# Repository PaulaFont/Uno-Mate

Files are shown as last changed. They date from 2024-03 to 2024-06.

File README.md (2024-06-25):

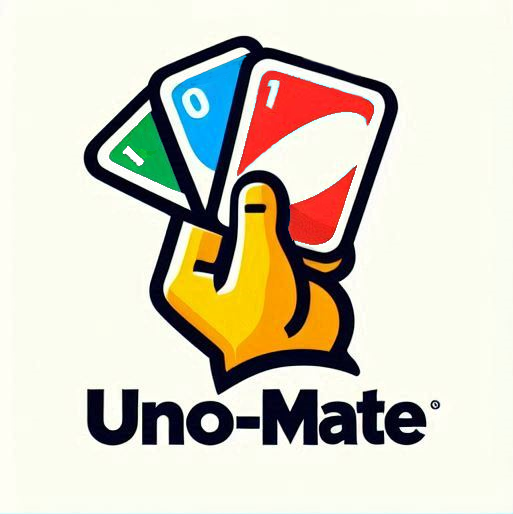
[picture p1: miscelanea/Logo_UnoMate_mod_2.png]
# Uno-Mate 

## Contendio del repositorio
- **3D_files**: Directorio que contiene todos los ficheros relativos al diseño 3D del robot
- **Fritzing**: Dentro de este tenemos todo el prototipaje de conexiones hecho en simulación
- **Pressupostos**: En el interior podemos encontrar los ficheros con la lista de componentes y sus respectivos precios
- **Sprints**: Aquí se encuentran todos los documentos relativos a los sprints
- **miscelanea**: Carpeta donde se encuentra archivos de recursos para el proyecto
- **src**: En esta carpeta es donde tenemos el código de nuestro robot

## Descripción del repositorio
### Contenido

1. [Descripcion](#descripcion)
2. [Como jugar una partida](#como-jugar-una-partida)
3. [Herramientas Software utilizadas](#herramientas-software-utilizadas)
4. [Esquema conexiones](#esquema-conexiones)
5. [Ficheros 3D](#ficheros-3d)
6. [Referencias](#referencias)
7. [Autores](#autores)

## Descripcion
<div style="text-align: justify;">

El objetivo del proyecto consiste en hacer el monitoreo de una partida del UNO, una de las cosas principales que hacemos en el proyecto es mirar cada una de las cartas que se van tirando en cada turno y por quién son tiradas, además de controlar si se hacen trampas o no. A más, otros objetivos del robot es que sea posible mezclar, repartir y dar diferentes cartas a los jugadores.

Para hacer el monitoreo de la partida lo que hemos hecho ha sido diferentes algoritmos. Uno que nos permite recortar la carta que está arriba del montón, y otros dos que nos permiten reconocer el número de la carta y el color de la carta.
Para hacer estos algoritmos hemos tenido que entrenar diferentes modelos. Para esto tuvimos que hacer un conjunto de datos customizado, ya que no encontrábamos ningún conjunto de datos que se ajustara a nuestra situación de las cartas del Uno. 

La funcionalidad de mezclar está diseñada para mezclar las cartas que se encuentran en las dos cajas laterales. En la caja de almacenaje de cartas (ubicada en el medio) se juntarán los dos bloques quedando completamente mezclados.
En el caso de repartir cartas, si el robot detecta que solo es necesario repartir una carta, se reparte una, si se detecta una carta de +2 se reparten dos cartas y para el caso del +4  se reparten  cuatro cartas.

Además, tendremos un audio que irá informando al jugador de los movimientos que puede hacer en cada momento.

En el caso de que la partida se acabe, lo que hacemos es guardar en la base de datos Firestore Database el historial de la partida, es decir, las cartas que se han tirado o robado, en qué turno, el día, la hora de la partida y el jugador que ha ganado. Este registro de partida estará disponible para todos los  participantes.

</div>

## Como jugar una partida

 1. Conectar el robot a la red eléctrica
 2. Conectar el robot a internet
 3. Establecer conexión entre la aplicación y el robot
 4. Empezar la partida desde la aplicación indicando los jugadores
 5. Seguir las instrucciones que el robot proporciona por voz
 6. Una vez finalizada la partida se puede consultar el historial a través de la app

## Herramientas Software utilizadas

- [Hardware (Fritzing)](https://github.com/PaulaFont/Uno-Mate/tree/main/Fritzing)

- [3D](https://www.tinkercad.com/)

- [Speech to text](https://cloud.google.com/speech-to-text/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)

## Esquema conexiones

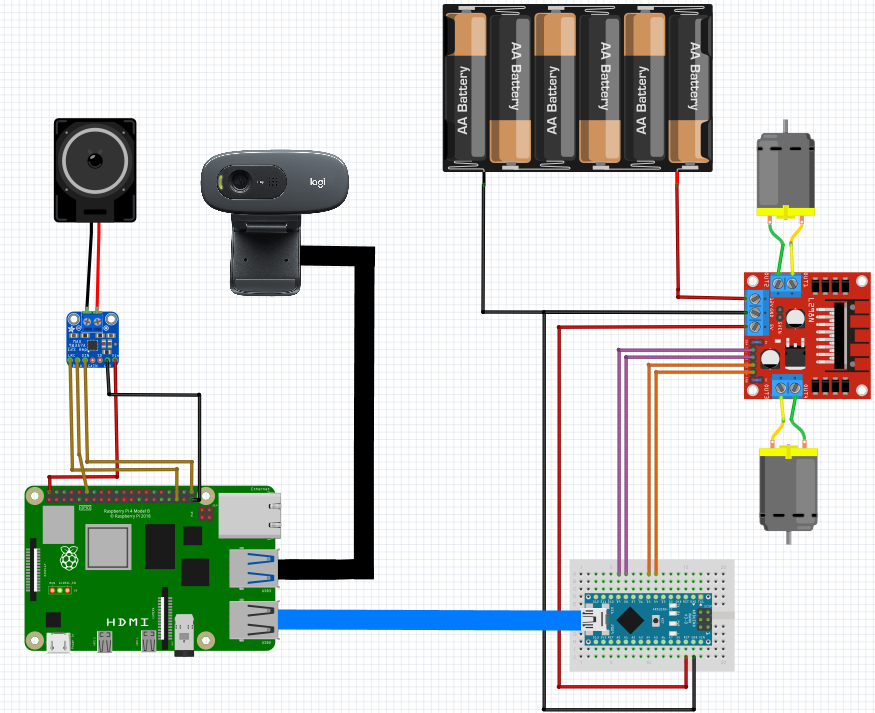
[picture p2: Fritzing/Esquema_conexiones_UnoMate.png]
Image text


## Ficheros-3D

Cajas de madera:
- Cajas de madera arriba : Tenemos los diseños de la plataforma donde jugaremos y las cajas de los laterales, donde irán las cartas.
- Caja de madera medio: En este fichero nos encontramos la caja del medio que será donde caerán las cartas.
- Caja en forma de U: En esta caja será donde pondremos todos los componentes de nuestro robot, además encima irán cada una de las cajas mencionadas anteriormente

Diseños 3D:
- Rampa para cartas 3D: En este fichero lo que tenemos es el modelo de rampa 3D que irá en cada una de las cajas laterales, que permitirá que las cartas salgan más fácilmente

## Referencias
- [Shuffle Inspiration Video](https://www.youtube.com/watch?v=kTARmpW6t8g)
- [Card Detector Github](https://github.com/EdjeElectronics/OpenCV-Playing-Card-Detector)
- [Similar Project RLP](https://rlpengineeringschooluab2023.wordpress.com/2023/06/06/slapbot/)

## Autores

- Rubén García Viciana (1634065)
- Marc Artero Pons (1632512)
- Carles Fornés Mas (1633536)
- Paula Font Solà (1633214)

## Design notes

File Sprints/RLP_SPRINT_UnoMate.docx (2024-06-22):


# UNO-MATE

Robot que asiste durante una partida del Uno, con nuevas incorporaciones como el control de tiempo, el registro de la partida y también permite mezclar las cartas automáticamente.

SPRINT FINAL.
DATE: 5 de junio del 2024

Rubén García Viciana (1634065)
Marc Artero Pons (1632512)
Carles Fornés Mas (1633536)
Paula Font Solà (1633214)

Tabla de contenidos

Descripción del proyecto 2

Componentes electrónicos 3

Esquema 4

Componentes extra y piezas 3D 6

Riesgos previstos y plan de contingencia 10

UNO-MATE

Robot que asiste durante una partida del Uno, con nuevas incorporaciones como el control de tiempo, el registro de la partida y también mezclar las cartas automáticamente.

# Descripción del proyecto

El objetivo del proyecto consiste en hacer el monitoreo de una partida del UNO, una de las cosas principales que hacemos en el proyecto es mirar cada una de las cartas que se van tirando en cada turno y por quién son tiradas, además de controlar si se hacen trampas o no. A más, otros objetivos del robot es que sea posible mezclar, repartir y dar diferentes cartas a los jugadores.

Para hacer el monitoreo de la partida lo que hemos hecho ha sido diferentes algoritmos. Uno que nos permite recortar la carta que está arriba del montón, y otros dos que nos permiten reconocer el número de la carta y el color de la carta.

Para hacer estos algoritmos hemos tenido que entrenar diferentes modelos. Para esto tuvimos que hacer un conjunto de datos customizado, ya que no encontrábamos ningún conjunto de datos que se ajustara a nuestra situación de las cartas del Uno.

La funcionalidad de mezclar está diseñada para mezclar las cartas que se encuentran en las dos cajas laterales. En la caja de almacenaje de cartas (ubicada en el medio) se juntarán los dos bloques quedando completamente mezclados.

En el caso de repartir cartas, si el robot detecta que solo es necesario repartir una carta, se reparte una, si se detecta una carta de +2 se reparten dos cartas y para el caso del +4 se reparten cuatro cartas.

Además, tendremos un audio que irá informando al jugador de los movimientos que puede hacer en cada momento.

En el caso de que la partida se acabe, lo que hacemos es guardar en la base de datos Firestore Database el historial de la partida, es decir, las cartas que se han tirado o robado, en qué turno, el día, la hora de la partida y el jugador que ha ganado. Este registro de partida estará disponible para todos los participantes.

# Componentes electrónicos

Esta es una lista de los componentes usados:

- Altavoz - Precio = 4,35€ - Unidades = 1 - Total = 4,35€
- Amplificador de audio I2S MAX98357A (3W) - Precio= 6,7€ - Unidades = 1 - Total = 4,35€
- Cámara - Precio= 20€ - Unidades = 1 - Total = 20€
- Motor - Precio= 5€- Unidades = 2 - Total = 10€
- Micro SD 32 GB - Precio= 6€- Unidades = 1 - Total = 6€
- Motor Controller TB6612FNG - Precio= 4,49€- Unidades = 1 - Total = 4,49€
- Font Alimentación Raspberry - Precio= 9,5€- Unidades = 1 - Total = 9,5€
- 6 pilas AA recargables - Precio= 11€- Unidades = 1 - Total = 11€
- Rueda de goma de 28mm con alta adherencia - Precio= 4,90€ - Unidades = 2 - Total = 9,8€

# Esquema


Conexiones Raspberry Pi:

- Conexiones USB:
  - Conexión con la webcam Logitech c270
  - Conexión con Arduino Nano
- Conexiones entre amplificador Adafruit MAX98357 y pines GPIO:

Amplificador MAX98357 | Raspberry Pi
Vin | 5V Power
GND | GND
DIN | GPIO 21
BCLK | GPIO 18
LRCLK | GPIO 19

Conexiones Arduino Nano:

- Conexiones entre controlador de motores l298n y Arduino nano:

L298N | Arduino Nano
IN1 | D9
IN2 | D10
IN3 | D11
IN4 | D12
5V | 5V
GND | GND

Conexiones del controlador de motores L298N:

- Conexiones internas:
  - Conexión entre ENA y 5 V para activar el primer motor
  - Conexión entre ENB y 5 V para activar el segundo motor
- Conexiones con motores:
  - Conexión de OUT1 y OUT2 con el primer motor
  - Conexión de OUT1 y OUT2 con el segundo motor
- Conexión con baterías:
  - Conexión con el positivo de la batería y VCC
  - Conexión con el negativo de la batería, el GND del Arduino Nano y el GND del Arduino Nano

# Componentes extra y piezas 3D

- Rampa de cartas - Unidades = 2
- Caja para repartir cartas - Unidades = 2
- Caja de almacenamiento de cartas - Unidades = 1
- Caja en forma de U - Unidades = 1
- Caja plataforma - Unidades = 1
- Sujeción para cámara - Unidades = 1

Rampa de cartas

Utilizamos esta impresión 3D para facilitar el recorrido de las cartas dentro de la caja, evitando que estas se atasquen entre sí y lleguen al hueco de salida de la caja más fácilmente. Esta pieza de impresión 3D se encuentra dentro de cada una de las cajas laterales.

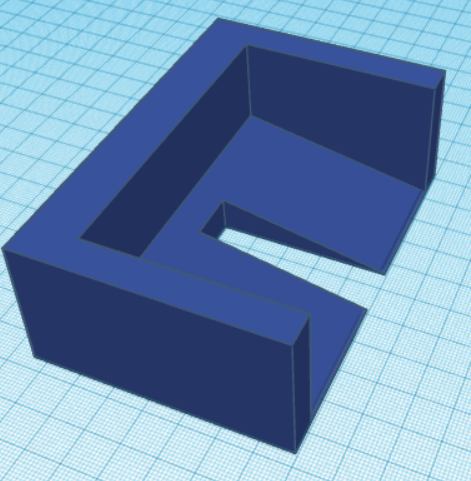
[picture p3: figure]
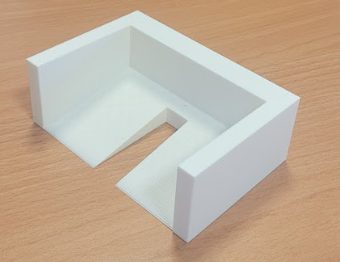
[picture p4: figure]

Caja para repartir cartas

Lo que tenemos para repartir cartas son 2 cajas iguales recortadas con cortadora láser. Esta caja tiene 2 huecos: uno que permite que las cartas salgan de manera lateral y otro por la parte de abajo que permite colocar la rueda que mueve las cartas. Tendremos estas dos cajas en los laterales.

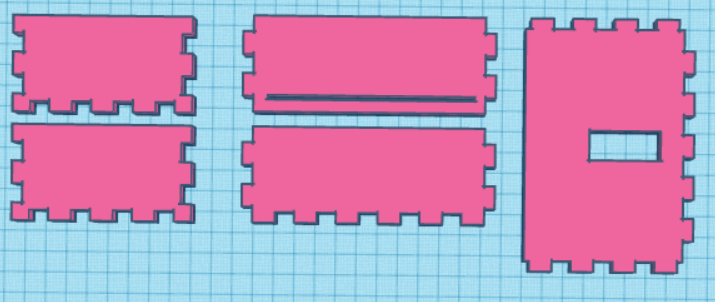
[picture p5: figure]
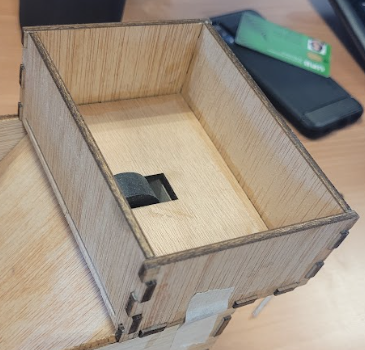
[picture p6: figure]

Caja de almacenamiento de cartas

En el centro del robot lo que nos encontramos es una caja sin paredes laterales, de tal manera que a los usuarios que están jugando les sea fácil meter la mano para sacar las cartas que se han repartido.

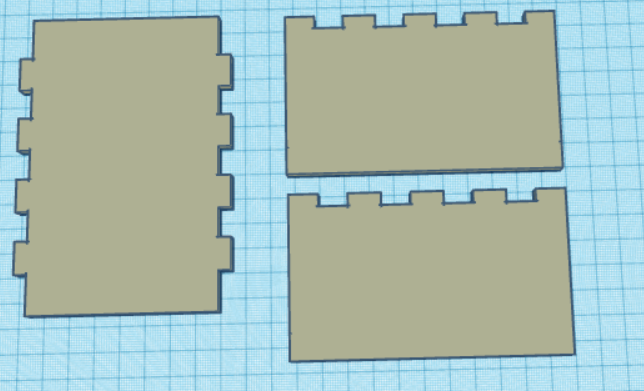
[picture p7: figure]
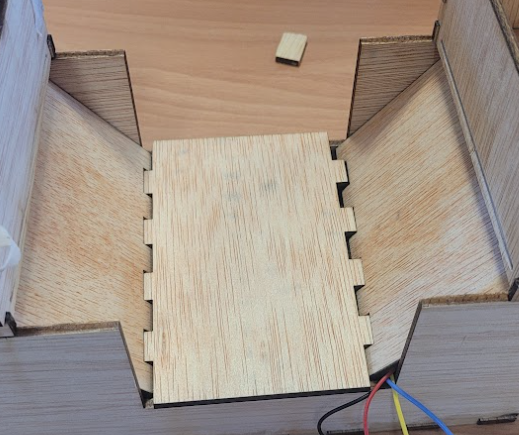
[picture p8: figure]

Caja en forma de U

En la parte inferior de la estructura lo que tenemos es una caja en forma de U que nos permite meter cada uno de los componentes que tenemos para nuestro robot y además sujetar toda la estructura de este.

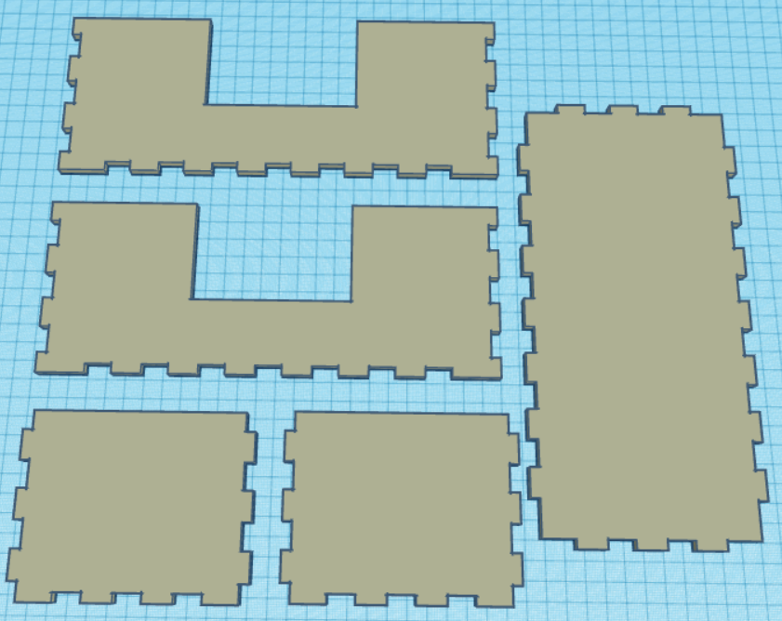
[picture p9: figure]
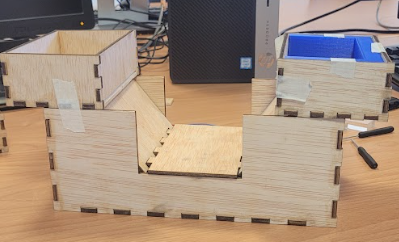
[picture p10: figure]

Caja plataforma

En la parte superior de la estructura lo que tenemos es una plataforma donde los jugadores pueden jugar una partida de Uno, de esta manera tienen un espacio cómodo para jugar y además la cámara podrá hacer un monitoreo de forma precisa.

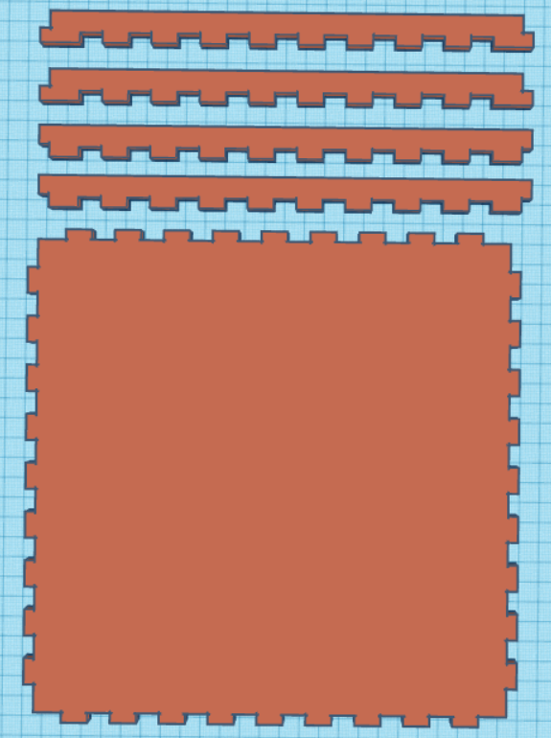
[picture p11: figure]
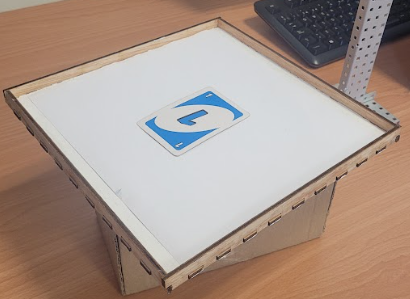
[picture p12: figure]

Sujeción para cámara

Para sujetar la webcam que hace la detección de cartas hemos creado una estructura a partir de unos hierros que nos proporcionaron en el laboratorio que nos permite tener la cámara a suficiente altura.

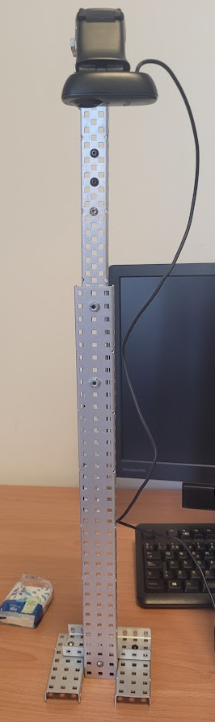
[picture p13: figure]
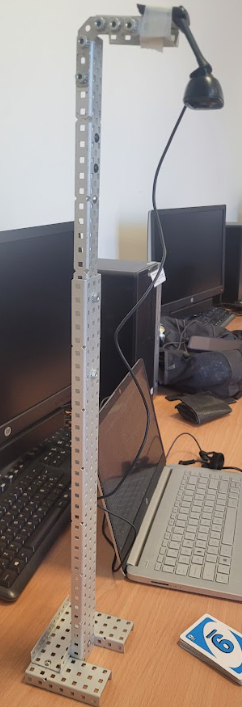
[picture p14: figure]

# Riesgos previstos y plan de contingencia

Risk # | Description | Probability (High/Medium /Low) | Impact (High/Medium /Low) | Contingency plan
1 | No sale 1 carta de forma consistente | Medium | Medium | Sale un poco y el usuario la coge
2 | No podemos ejecutar el algoritmo de forma completa en la Raspberry Pi | Low | High | Mover esas partes del código que no hemos sido capaces de ejecutar a una Cloud Function
3 | Al mezclar las cartas se quedan atascadas | Low | Medium | En vez de intentar-lo hacer rápidamente ir sacando cartas poco a poco para que no se queden atascadas

Referencias

Este proyecto se ha inspirado utilizando los siguientes proyectos que hemos encontrado en Internet:

Shuffle Inspiration Video

https://www.youtube.com/watch?v=kTARmpW6t8g

Card Detector Github

https://github.com/EdjeElectronics/OpenCV-Playing-Card-Detector

Similar Project RLP

https://rlpengineeringschooluab2023.wordpress.com/2023/06/06/slapbot/

UNO-MATE

RLP - Computer Engineering. UAB (Barcelona) 2023-2024

Sprint Final Date: 05 Junio 2024

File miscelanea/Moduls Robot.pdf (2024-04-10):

MÒDUL DE VISIÓ

- Utilitza una càmera per capturar l’estat actual del joc i analitzar les cartes tirades
- Detectar gestos de les mans per donar ordres al robot

MÒDUL DE DETECCIÓ D’ERRORS

- Controla que les normes de l’UNO es respecten durant la partida
- En cas de tirar una carta que no correspon s’activa una senyal d’error

MÒDUL DE RECONEIXEMENT DE VEU

- Reconeixement de la veu de l’usuari per seleccionar el mode de joc desitjat

MÒDUL SPEECH TO TEXT

- Interpreta i tradueix les comandes de veu a text per poder processar les ordres donades

MÒDUL PANTALLA DE TEMPS

- Gestiona el temporitzador de cada turn, mostrant el temps restant a la pantalla
- Mostra en quin estat de la partida estem (Barrejant, Pausa, etc)

MÒDUL DE SEGUIMENT DEL JOC

- Monitoriza i registra el progrés de la partida, incloent-hi l’estat de les cartes en cada torn i qualsevol canvi de mode en el transcurs de la partida com per exemple posar pausa

MÒDUL DE REPARTIR CARTES

- Controla els servomotors encarregats de moure les rodes que s’encarreguen de repartir les cartes cap als costats

MÒDUL DE BARREJAR CARTES

- Controla els servomotors encarregats de moure les rodes que s’encarreguen de barrejar les cartes.
- Implementa algorismes per repartir cartes de forma equitativa i garantitzar una barreja aleatoria

MÒDUL DE GESTIÓ DE L’ORDRE JOC

- Controla els torns de cada persona durant la partida
- Mantenir un estat coherent de la partida

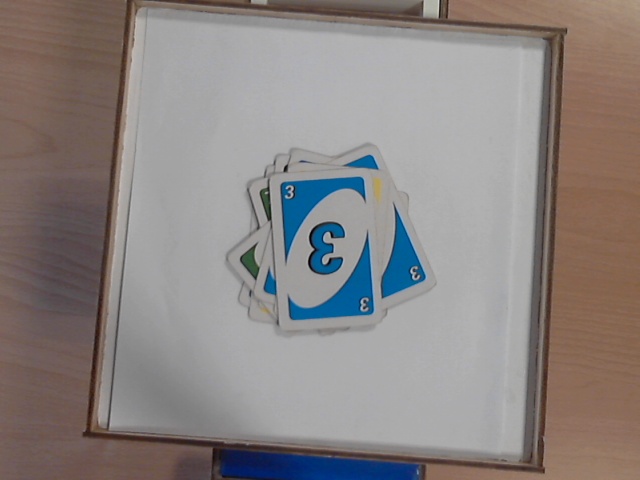
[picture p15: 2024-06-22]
src/Raspberry_pi_code/frame.jpg

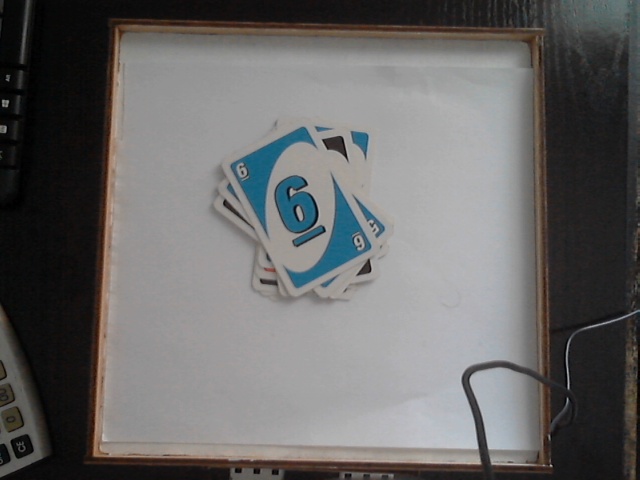
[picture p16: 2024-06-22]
src/Raspberry_pi_code/video_partida/frame9.jpg

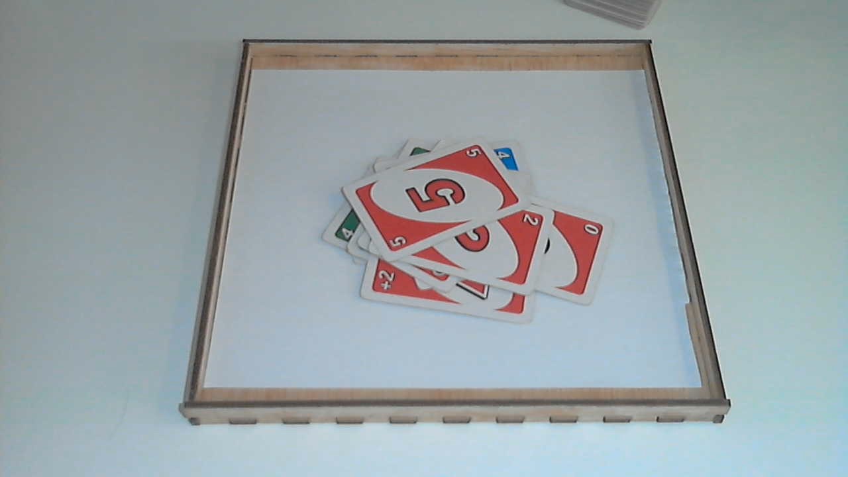
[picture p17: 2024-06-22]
src/Raspberry_pi_code/prova_partida_entrega/WIN_20240517_11_44_29_Pro.jpg

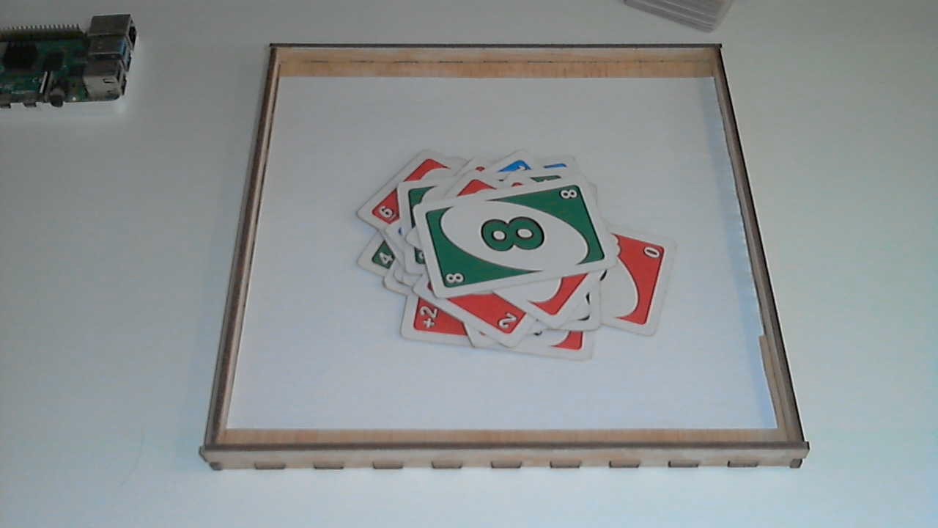
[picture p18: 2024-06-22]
src/Raspberry_pi_code/prova_partida_entrega/WIN_20240517_11_53_14_Pro.jpg

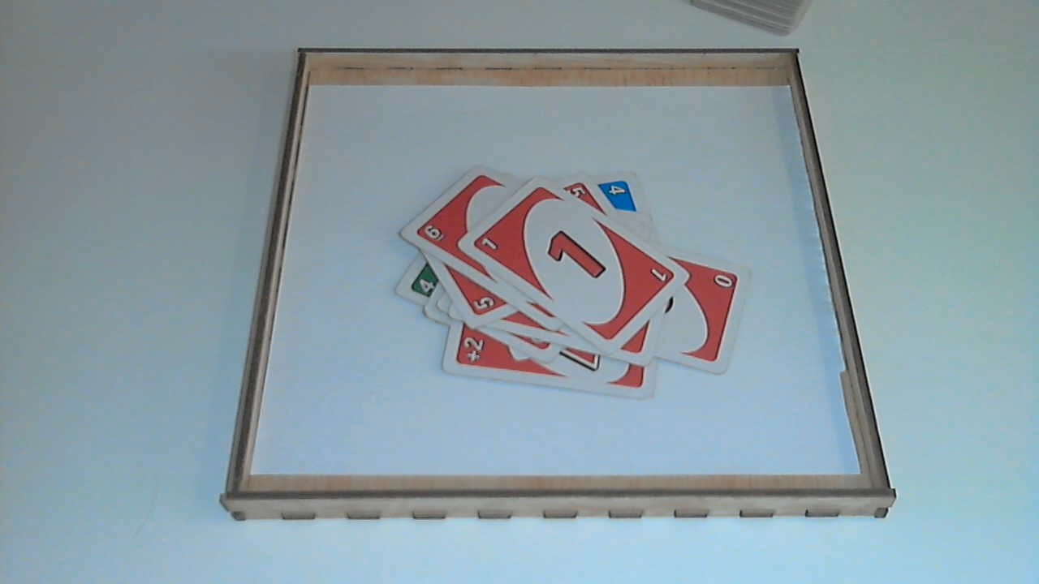
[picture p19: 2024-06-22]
src/Raspberry_pi_code/prova_partida_entrega/WIN_20240517_11_46_41_Pro.jpg

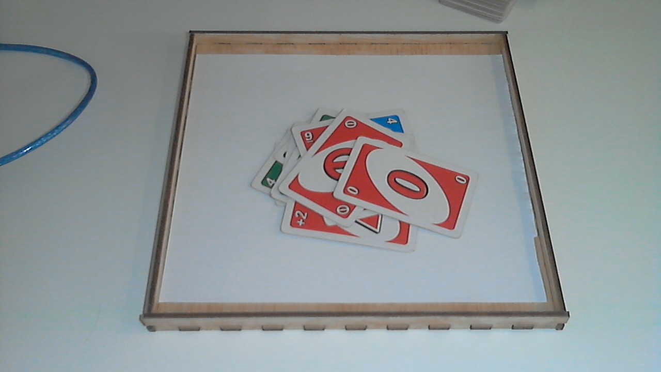
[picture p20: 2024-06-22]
src/Raspberry_pi_code/prova_partida_entrega/WIN_20240517_11_42_58_Pro.jpg

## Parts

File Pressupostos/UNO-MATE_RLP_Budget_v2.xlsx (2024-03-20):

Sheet: Bricogeek
Name: UNO-MATE | Price | Units | Total | URL
Altaveu | €4.35 | 1.00 | €4.35 | https://tienda.bricogeek.com/varios/938-altavoz-con-caja-3w.html
Amplificador de audio I2S MAX98357A (3W) | €6.70 | 1.00 | €6.70 | https://tienda.bricogeek.com/accesorios-raspberry-pi/867-amplificador-de-audio-i2s-max98357a-3w.html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
Matriu 8x8 LEDs | €5.75 | 1.00 | €5.75 | https://tienda.bricogeek.com/led-neopixel/1694-panel-led-rgb-8x8-ws2812b.html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
Càmera | €20.00 | 1.00 | €20.00 | Link Amazon (https://www.amazon.es/Logitech-Video-Llamadas-Correcci%C3%B3n-Iluminaci%C3%B3n-Chromebook/dp/B01BGBJ8Y0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)
Motor | €5.00 | 2.00 | €10.00 | https://tienda.bricogeek.com/motores-dc/1832-motor-n20-con-reductora-metalica-6v-50-rpm.html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
Micro SD 32 GB | €6.00 | 1.00 | €6.00 | https://tienda.bricogeek.com/accesorios-raspberry-pi/789-memoria-microsd-32gb-clase-10-8806088676562.html
Motor Controller TB6612FNG | €4.95 | 1.00 | €4.95 | https://tienda.bricogeek.com/controladores-motores/999-controlador-de-motores-tb6612fng.html
Font Alimentació Raspberry | €9.50 | 1.00 | €9.50 | https://tienda.bricogeek.com/home/1331-fuente-alimentacion-raspberry-pi-4-usb-c-51v-3a.html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
6 piles AA recargables | €11.00 | 1.00 | €11.00 | Link Amazon (https://www.amazon.es/Varta-Recharge-recargable-materiales-reciclados/dp/B07F6LFLK1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)
Rueda de goma de 28mm con alta adherencia | €4.90 | 2.00 | €9.80 | https://tienda.bricogeek.com/ruedas-robotica/1008-rueda-solarbotics-rw2i.html?search_query=rueda&results=48
TOTAL |  |  | €88.05

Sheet: Electan
Name | Price | Units | Total | URL
Portapiles (6xAA) (alimentació motors) | €3.85 | 1.00 | €3.85 | https://www.electan.com/portapilas-pilas-con-conector-para-arduino-p-3175.html
TOTAL |  |  | €3.85

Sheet: Farnell
Name | Price | Units | Total | URL
Arduino Nano Every | €11.00 | 1.00 | €11.00 | https://es.farnell.com/arduino/abx00028/placa-desarrollo-nano-every-mcu/dp/3404690
Raspberry Pi4 B 4GB | €49.80 | 1.00 | €49.80 | https://es.farnell.com/raspberry-pi/rpi4-modbp-4gb/raspberry-pi-4-model-b-4gb/dp/3051887
TOTAL |  |  | €60.80

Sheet: Diotronic
Name | Price | Units | Total | URL
TOTAL |  |  | 0

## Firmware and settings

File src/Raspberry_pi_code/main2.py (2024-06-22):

import clases
import firebase
import funcions_logica as funcions
import algorisme_final
print("HOLA antes")
import funcions_raspberry
print("HOLA despues")
import time
import cv2
import threading
import random


COLORS_DISPONIBLES = ["red", "blue", "green", "yellow"]
# funcions.texto_a_audio("Repartiendo cartas iniciales", "audios/repartir_inicials.mp3")
# funcions.executar_mp3_sin_borrar("audios/repartir_inicials.mp3")

# Pillar els jugadors que ens passa l'arduino que rep per bluetooth
mails = funcions.get_mails()
jugadors = []
for mail in mails:
    jugador = firebase.get_nom("usuarios", mail)
    jugadors.append(jugador)

partida = clases.Partida(jugadors)  # Crear la partida

# funcions.borrar_txt()

for jugador in partida.jugadors:
    print(jugador.torn_jugador)
    print(jugador.nom)
print("IMPORTS HECHOS")

# Repartir les cartes
funcions_raspberry.repartir_cartes_inicials(len(partida.get_jugadors()))
print("IMPORTS HECHOS2")

funcions.texto_a_audio("Los jugadores son.", 'nom.mp3')
funcions.executar_mp3("nom.mp3")
for jugador in partida.jugadors:
    funcions.texto_a_audio(str(jugador.nom), 'nom.mp3')
    funcions.executar_mp3("nom.mp3")

# Primera carta
cap = cv2.VideoCapture(0)  # Mantenir la cÃ mera oberta tota la estona ja que tarda molt en obrir i tancar
cap.release()
funcions.nou_frame(cap)
print("Colocar carta inicial")
carta_tirada = False
coordenades = []
while not carta_tirada:  # Mentre que no s'ha posat i detectat la primera carta del tauler no seguim
    funcions.executar_mp3_sin_borrar("audios/colocar_inicial.mp3")
    frame = funcions.nou_frame(cap)  # Trec una nova captura de la camara per buscar la carta cada 3 segons
    figura, color, coordenades = algorisme_final.detectar_carta(frame)
    if figura != "Null" and color != "Null":
        carta_tirada = True  # Un cop tenim la primera carta detectada ja seguim
        carta = clases.Carta(color, figura, "Carta Inicial")
        partida.pila_joc.append(carta)  # Guardar la primera carta al stack
        partida.historial.append(carta)  # l'Historial es el que penjarem al firebase i la pila de joc per controlar
    else:
        time.sleep(3)

print("Valor de la carta: " + str(partida.pila_joc[0].valor))
print("Color de la carta: " + str(partida.pila_joc[0].color))

# ComenÃ§a l'algorisme

acabar_partida = False
finalitzar_primera_jugada = False
coordenades_anteriors = coordenades

while not acabar_partida:
    finalitzar_torn = False
    finalitzar_primera_jugada = False
    print("Torn de " + str(partida.jugadors[partida.torn_actual].nom))
    funcions.texto_a_audio("Turno de " + str(partida.jugadors[partida.torn_actual].nom), 'nom.mp3')
    funcions.executar_mp3("nom.mp3")
    print("primer torn")
    # posar aqui un while de la part d'escoltar 5 segons i veure si es la mateixa carta, fins que no digui robar o tiri
    # no seguira amb la resta de torns que sera el bucle d'abaix normal com fins ara
    while not finalitzar_primera_jugada:
        # Aqui tiraria la carta el jugador o dir "Robar" si no te carta, ho faig amb threads per escoltar a la vegada
        robar_carta = [False]
        parar_escoltar = [False]  # Lista para pasar el valor por referencia
        thread2 = threading.Thread(target=funcions.escoltar_robar, args=(parar_escoltar, robar_carta,))
        thread1 = threading.Thread(target=funcions.wait_and_stop, args=(parar_escoltar,))
        thread1.start()
        thread2.start()
        thread1.join()
        thread2.join()

        if robar_carta[0]:  # En cas d'haver de robar una carta passem de torn
            finalitzar_primera_jugada = True
            finalitzar_torn = True
            if partida.cartes_a_robar == 0:
                partida.cartes_a_robar += 1
            partida.cadena_robar = False
            funcions_raspberry.repartir_n_cartes(partida.cartes_a_robar)
            partida.jugadors[partida.torn_actual].num_cartes += partida.cartes_a_robar  # Li sumem les cartes a robar
            carta = clases.Carta("", "", str(partida.jugadors[partida.torn_actual].nom))
            partida.historial.append(carta)  # NomÃ©s l'afegim al historial ja que sino ens afecta a la logica
            partida.cartes_a_robar = 0
            break

        carta_tirada = False
        while not carta_tirada:  # Mentre que no s'ha posat i detectat la primera carta del tauler no seguim
            frame = funcions.nou_frame(cap)  # Trec una nova captura de la camara per buscar la carta cada 3 segons
            figura, color, coordenades = algorisme_final.detectar_carta(frame)
            if figura != "Null" and color != "Null":
                carta_tirada = True  # Un cop tenim la primera carta detectada ja seguim
                carta = clases.Carta(color, figura, str(partida.jugadors[partida.torn_actual].nom))
            else:
                funcions.executar_mp3_sin_borrar("audios/carta_no_identificada.mp3")
                time.sleep(3)
                print("No s'ha detectat la carta")

        print("Valor de la carta: " + str(carta.valor))
        print("Color de la carta: " + str(carta.color))
        # Comprovo que no sigui la mateixa carta d'abans
        mateixes_coordenades = funcions.comprovar_coordenades_i_carta(coordenades_anteriors, coordenades, carta.valor,
                                                                      carta.color, partida)
        if mateixes_coordenades:  # Si les coordenades son les mateixes repetim el bucle, aixi fins que tiri o robi
            funcions.executar_mp3_sin_borrar("audios/carta_no_tirada.mp3")
            print("NO HA TIRAT CARTA, REPETIM BUCLE")
            continue
        print("HA TIRAT CARTA, MIREM SI ES VALID")
        moviment_valid = funcions.moviment_legal_inicial(carta, partida)  # Mirar si la carta tirada es valida
        if moviment_valid:  # Si el moviment es valid
            print("MOVIMENT VALID")
            funcions.executar_mp3_sin_borrar("audios/moviment_valid.mp3")
            coordenades_anteriors = coordenades  # Si les coordenades no son les mateixes, posem les noves com anteriors
            finalitzar_primera_jugada = True
            partida.jugadors[partida.torn_actual].num_cartes -= 1  # Li restem una carta de la mÃ 
            if carta.color == "Wild":  # Si la carta tirada es Wild hem d'especificar quin color volem
                funcions.executar_mp3_sin_borrar("audios/dir_color_wild.mp3")
                ha_dit_color = False
                while not ha_dit_color:  # Fins que no es digui un color valid preguntarem pel color de la carta
                    color_detectat = funcions.escoltar_color()
                    if color_detectat.lower() in COLORS_DISPONIBLES:  # Si el color es valid:
                        funcions.executar_mp3_sin_borrar("audios/color_valid.mp3")
                        carta.color_wild = color_detectat.lower()  # Assignar el color de la carta wild
                        ha_dit_color = True
                    else:
                        print("Color no vàlid. Repeteix el color")
                        funcions.executar_mp3_sin_borrar("audios/color_no_valid.mp3")
            if carta.valor == "Reverse":
                partida.direccio = 1 - partida.direccio
            if carta.valor == "Skip":
                partida.skips_acumulats += 1
            if carta.valor == "Draw4":
                partida.cadena_robar = True
                partida.cartes_a_robar += 4
            if carta.valor == "Draw2":
                partida.cadena_robar = True
                partida.cartes_a_robar += 2

            partida.pila_joc.append(carta)  # Si el moviment es valid, guardem la carta al stack
            partida.historial.append(carta)

        else:
            print("MOVIMENT ILEGAL")
            funcions.executar_mp3_sin_borrar("audios/moviment_ilegal.mp3")
            # si el moviment no es valid el robot pitara i s'haura de treure la carta
            funcions_raspberry.repartir_n_cartes(partida.cartes_a_robar + 2)
            partida.cartes_a_robar = 0
            restaurar_carta = False
            while not restaurar_carta:
                print("carta no restaurada")
                funcions.executar_mp3_sin_borrar("audios/quitar_carta_ilegal.mp3")
                time.sleep(1)
                frame = funcions.nou_frame(cap)
                figura, color, coordenades = algorisme_final.detectar_carta(frame)
                carta = clases.Carta(color, figura, str(partida.jugadors[partida.torn_actual].nom))
                if carta.valor == partida.pila_joc[-1].valor and carta.color == partida.pila_joc[-1].color:
                    restaurar_carta = True
            finalitzar_torn = True
            finalitzar_primera_jugada = True
            partida.cadena_robar = False
            print("carta restaurada")
            funcions.executar_mp3_sin_borrar("audios/ilegal_restaurat.mp3")

        ha_guanyat = funcions.check_victoria(partida.jugadors[partida.torn_actual])
        if ha_guanyat:
            partida.jugadors[partida.torn_actual].ganador = True
            document_existeix = True
            id_joc = "Null"
            while document_existeix:
                id_joc = "id_" + str(random.randint(0, 100000))

                
                existencia = firebase.get_document('partidas', id_joc)

                if existencia is None:
                    document_existeix = False
            data = funcions.dades_partida(partida, mails)
            firebase.save_game(id_joc, data)
            funcions.act_player_data(partida, mails)
            acabar_partida = True
            funcions.texto_a_audio("Partida finalizada. El jugador "
                                   + str(partida.jugadors[partida.torn_actual].nom) + " ha ganado la partida", 'fin.mp3')
            funcions.executar_mp3("fin.mp3")
            funcions.texto_a_audio("Partida guardada con id "
                                   + str(id_joc), 'id.mp3')
            funcions.executar_mp3("id.mp3")
            finalitzar_torn = True

    if finalitzar_torn is True:
        funcions.actualitzar_torns(partida)
        continue
    while not finalitzar_torn:
        funcions.executar_mp3_sin_borrar("audios/tirar_segon_torn.mp3")
        time.sleep(1)  # esperem 2 segons

        carta_tirada = False
        print("segona jugada")
        while not carta_tirada:  # Mentre que no s'ha posat i detectat la primera carta del tauler no seguim
            frame = funcions.nou_frame(cap)  # Trec una nova captura de la camara per buscar la carta cada 3 segons
            figura, color, coordenades = algorisme_final.detectar_carta(frame)
            if figura != "Null" and color != "Null":
                carta_tirada = True  # Un cop tenim la primera carta detectada ja seguim
                carta = clases.Carta(color, figura, str(partida.jugadors[partida.torn_actual].nom))
            else:
                funcions.executar_mp3_sin_borrar("audios/carta_no_identificada.mp3")
                time.sleep(3)
                print("No s'ha detectat la carta")

        # si les coordenades son les mateixes cambio de torn, sino pot seguir tirant
        mateixes_coordenades = funcions.comprovar_coordenades_i_carta(coordenades_anteriors, coordenades, carta.valor,
                                                                      carta.color, partida)
        if mateixes_coordenades:  # Si les coordenades son les mateixes no hem tirat carta i per tant passa de torn
            print("NO HA TIRAT RES MES PER TANT S'ACABA EL TORN")
            funcions.executar_mp3_sin_borrar("audios/carta_no_tirada.mp3")
            finalitzar_torn = True
            break
        print("NOVA CARTA, CONTINUA EL SEU TORN")

        print("Valor de la carta: " + str(carta.valor))
        print("Color de la carta: " + str(carta.color))
        moviment_valid = funcions.moviment_legal_continuacio(carta, partida)  # Mirar si la carta tirada es valida
        if moviment_valid:  # Si el moviment Ã©s vÃ lid
            print("MOVIMENT VALID")
            funcions.executar_mp3_sin_borrar("audios/moviment_valid.mp3")
            coordenades_anteriors = coordenades  # Si les coordenades no son les mateixes, posem les noves com anteriors
            partida.jugadors[partida.torn_actual].num_cartes -= 1  # Li restem una carta de la mÃ 
            print("N cartes: " + str(partida.jugadors[partida.torn_actual].num_cartes))
            if carta.color == "Wild":  # Si la carta tirada es Wild hem d'especificar quin color volem
                funcions.executar_mp3_sin_borrar("audios/dir_color_wild.mp3")
                ha_dit_color = False
                while not ha_dit_color:  # Fins que no es digui un color valid preguntarem pel color de la carta
                    color_detectat = funcions.escoltar_color()
                    if color_detectat.lower() in COLORS_DISPONIBLES:  # Si el color es valid:
                        funcions.executar_mp3_sin_borrar("audios/color_valid.mp3")
                        carta.color_wild = color_detectat.lower()  # Assignar el color de la carta wild
                        ha_dit_color = True
                    else:
                        funcions.executar_mp3_sin_borrar("audios/color_no_valid.mp3")
                        print("Color no vÃ lid. Repeteix el color")
            if carta.valor == "Reverse":
                partida.direccio = 1 - partida.direccio
            if carta.valor == "Skip":
                partida.skips_acumulats += 1
            if carta.valor == "Draw4":
                partida.cadena_robar = True
                partida.cartes_a_robar += 4
            if carta.valor == "Draw2":
                partida.cadena_robar = True
                partida.cartes_a_robar += 2

            partida.pila_joc.append(carta)  # Si el moviment es valid, guardem la carta al stack
            partida.historial.append(carta)

        else:
            print("MOVIMENT ILEGAL")
            funcions.executar_mp3_sin_borrar("audios/moviment_ilegal.mp3")
            # si el moviment no es valid el robot pitarÃ  i s'haura de treure la carta
            funcions_raspberry.repartir_n_cartes(2)
            partida.cartes_a_robar = 0
            restaurar_carta = False
            while not restaurar_carta:
                print("carta no restaurada")
                funcions.executar_mp3_sin_borrar("audios/quitar_carta_ilegal.mp3")
                time.sleep(1)
                frame = funcions.nou_frame(cap)
                figura, color, coordenades = algorisme_final.detectar_carta(frame)
                carta = clases.Carta(color, figura, str(partida.jugadors[partida.torn_actual].nom))
                if carta.valor == partida.pila_joc[-1].valor and carta.color == partida.pila_joc[-1].color:
                    restaurar_carta = True
            finalitzar_torn = True
            finalitzar_primera_jugada = True
            partida.cadena_robar = False
            print("carta restaurada")
            funcions.executar_mp3_sin_borrar("audios/ilegal_restaurat.mp3")

        ha_guanyat = funcions.check_victoria(partida.jugadors[partida.torn_actual])
        if ha_guanyat:
            
            partida.jugadors[partida.torn_actual].ganador = True
            document_existeix = True
            id_joc = "Null"
            while document_existeix:
                id_joc = "id_" + str(random.randint(0, 100000))
                existencia = firebase.get_document('partidas', id_joc)
                if existencia is None:
                    document_existeix = False
            data = funcions.dades_partida(partida, mails)
            firebase.save_game(id_joc, data)
            funcions.act_player_data(partida, mails)
            finalitzar_torn = True
            funcions.texto_a_audio("Partida finalizada. El jugador "
                                   + str(partida.jugadors[partida.torn_actual].nom) + " ha ganado la partida", 'fin.mp3')
            funcions.executar_mp3("fin.mp3")
            funcions.texto_a_audio("Partida guardada con id "
                                   + str(id_joc), 'id.mp3')
            funcions.executar_mp3("id.mp3")
            acabar_partida = True
    funcions.actualitzar_torns(partida)

print("PARTIDA FINALITZADA")
print("PARTIDA GUARDADA AMB ID: " + str(id_joc))

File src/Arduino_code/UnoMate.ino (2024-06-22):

const int IN1_PIN = 9; // The Arduino Nano pin connected to the IN1 pin L298N
const int IN2_PIN = 10; // The Arduino Nano pin connected to the IN2 pin L298N
const int IN3_PIN = 11; // The Arduino Nano pin connected to the IN1 pin L298N
const int IN4_PIN = 12;  

void setup() {
  // Initialize digital pins as outputs
  pinMode(IN1_PIN, OUTPUT);
  pinMode(IN2_PIN, OUTPUT);
  pinMode(IN3_PIN, OUTPUT);
  pinMode(IN4_PIN, OUTPUT);
  Serial.begin (9600);

}

void endavant(int pin1, int pin2, int temps) {
  digitalWrite(pin1, HIGH); 
  digitalWrite(pin2, LOW);

  if(temps != 0){
    delay(temps);
  }
}

void enrrera(int pin1, int pin2, int temps) {
  digitalWrite(pin1, LOW); 
  digitalWrite(pin2, HIGH);

  if(temps != 0){
    delay(temps);
  }
}

void pararMotors(int pin1, int pin2){
  digitalWrite(pin1, LOW); 
  digitalWrite(pin2, LOW);
}

void endavantv2(int pin1, int pin2, int pin3, int pin4, int temps) {
  digitalWrite(pin1, HIGH); 
  digitalWrite(pin2, LOW);
  digitalWrite(pin3, HIGH); 
  digitalWrite(pin4, LOW);

  if(temps != 0){
    delay(temps);
  }
}

void enrrerav2(int pin1, int pin2, int pin3, int pin4, int temps) {
  digitalWrite(pin1, LOW); 
  digitalWrite(pin2, HIGH);
  digitalWrite(pin3, LOW);
  digitalWrite(pin4, HIGH);

  if(temps != 0){
    delay(temps);
  }
}

void pararMotorsv2(int pin1, int pin2, int pin3, int pin4){
  digitalWrite(pin1, LOW); 
  digitalWrite(pin2, LOW);
  digitalWrite(pin3, LOW); 
  digitalWrite(pin4, LOW);
}

/*
Robar "num" cartes de un dels dos motors.
*/
void robar(int pin1, int pin2, int num){
  int var = 0;
  while(var < num){
    enrrera(pin1, pin2, 80);
    endavant(pin1, pin2, 120);
    enrrera(pin1, pin2, 80);
    pararMotors(pin1, pin2);
    delay(1000);
    var++;
  }
}

void loop() {
    if (Serial.available() > 0) {
      String message = Serial.readStringUntil('\n'); // Lee el mensaje hasta un salto de l�nea
      int numero = message.toInt(); // Convierte el mensaje a un n�mero entero
      if (numero == 0) { //BARREJAR
        endavantv2(IN1_PIN, IN2_PIN, IN3_PIN, IN4_PIN, 1000);
        pararMotorsv2(IN1_PIN, IN2_PIN, IN3_PIN, IN4_PIN);
      }
      else {
        robar(IN1_PIN, IN2_PIN, numero);
      }
    }
}



//Altres funcions
/*
void barrejarv2(int pin1, int pin2, int pin3, int pin4){
  int var = 0;
  while(var < 20){
    enrrera(IN1_PIN, IN2_PIN, 100);
    endavant(IN1_PIN, IN2_PIN, 200);
    enrrera(IN1_PIN, IN2_PIN, 100);
    pararMotorsv2(IN1_PIN, IN2_PIN, IN3_PIN, IN4_PIN);
    delay(100);
    enrrera(IN3_PIN, IN4_PIN, 100);
    endavant(IN3_PIN, IN4_PIN, 200);
    enrrera(IN3_PIN, IN4_PIN, 100);
    pararMotorsv2(IN1_PIN, IN2_PIN, IN3_PIN, IN4_PIN);
    delay(100);
    var++;
  }
}


// La idea es barrejar traient 2 o 3 cartes d'una banda cada cop
// De moment per provar es repetiria 10 vegades

void barrejar(int pin1, int pin2, int pin3, int pin4){
  int var = 0;
  while(var < 10){
    //Nomes treu cartes una banda
    digitalWrite(pin1, HIGH); 
    digitalWrite(pin2, LOW);
    digitalWrite(pin3, LOW); 
    digitalWrite(pin4, LOW);
    delay(200);
    //Nomes treu cartes l'altra banda
    digitalWrite(pin1, LOW); 
    digitalWrite(pin2, LOW);
    digitalWrite(pin3, HIGH); 
    digitalWrite(pin4, LOW);
    delay(200);
    var++;
  }
}
*/

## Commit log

2024-03-20 Rename Fritzing/Arduino Nano Every.fzpz to Fritzing/moduls/Arduino Nano Every.fzpz
2024-03-20 Rename Fritzing/WS2812 RGB LED matrix 8x8.fzpz to Fritzing/moduls/WS2812 RGB LED matrix 8x8.fzpz
2024-06-22 Cajas de madera
    En cada uno de los ficheros tenemos:
    - Cajas de madera arriba : Tenemos la plataforma donde jugaremos, y las cajas de los laterales donde irán las cartas
    - Caja de madera medio: Lo que tenemos es la caja del medio que serán donde caeran las cartas
    - Caja en forma de U: Aqui será donde pondremos todos los componentes de nuestro robot, además encima irán cada una de las cartas mendionadas anteriormente
2024-06-22 Rampa para cartas 3D
    En este caso lo que hicimos fue imprimir dos veces el mismo modelo 3D para cada una de las cajas que teniamos en los laterales.
